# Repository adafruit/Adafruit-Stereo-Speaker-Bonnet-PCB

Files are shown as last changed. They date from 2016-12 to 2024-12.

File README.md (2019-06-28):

## Adafruit Stereo Speaker Bonnet PCB

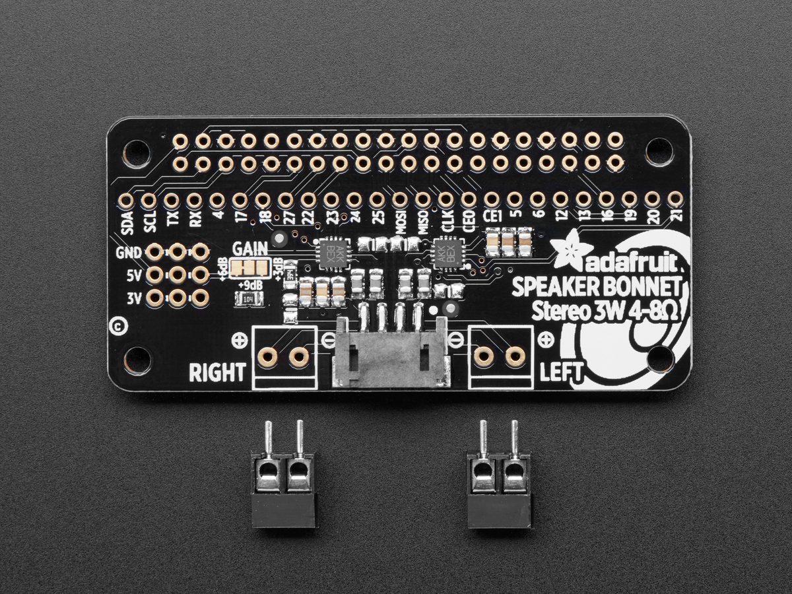
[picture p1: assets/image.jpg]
<a href="http://www.adafruit.com/products/3346"><br/>
Click here to purchase one from the Adafruit shop</a>

PCB files for the Adafruit Stereo Speaker Bonnet for Raspberry Pi. Format is EagleCAD schematic and board layout
* http://www.adafruit.com/product/3346

### Description

Hey Mr. DJ! Turn up that Raspberry Pi mix to the max with this cute 3W Stereo Amplifier Bonnet for Raspberry Pi. (It's not big enough to be an official HAT, so we called it a bonnet, you see?) It's the exact same size as a Raspberry Pi Zero but works with any and all Raspberry Pi computers with a 2x20 connector - A+, B+, Zero, Pi 2, Pi 3, etc. We've tested it out with Raspbian (the official operating system) and Retropie.

This Bonnet uses I2S a digital sound standard, so you get really crisp audio. The digital data goes right into the amplifier so there's no static like you hear from the headphone jack. And it's super easy to get started. Just plug in any 4Ω to 8Ω speakers, up to 3 Watts, run our installer script on any Raspberry Pi, reboot and you're ready to jam!

Each order comes as a fully tested and assembled PCB and 2x extra terminal blocks. No soldering required if you're using our 3 Watt speaker set, just plug and play.

### License

Adafruit invests time and resources providing this open source design, please support Adafruit and open-source hardware by purchasing products from [Adafruit](https://www.adafruit.com)!

Designed by Limor Fried/Ladyada for Adafruit Industries.

Creative Commons Attribution/Share-Alike, all text above must be included in any redistribution. See license.txt for additional details.

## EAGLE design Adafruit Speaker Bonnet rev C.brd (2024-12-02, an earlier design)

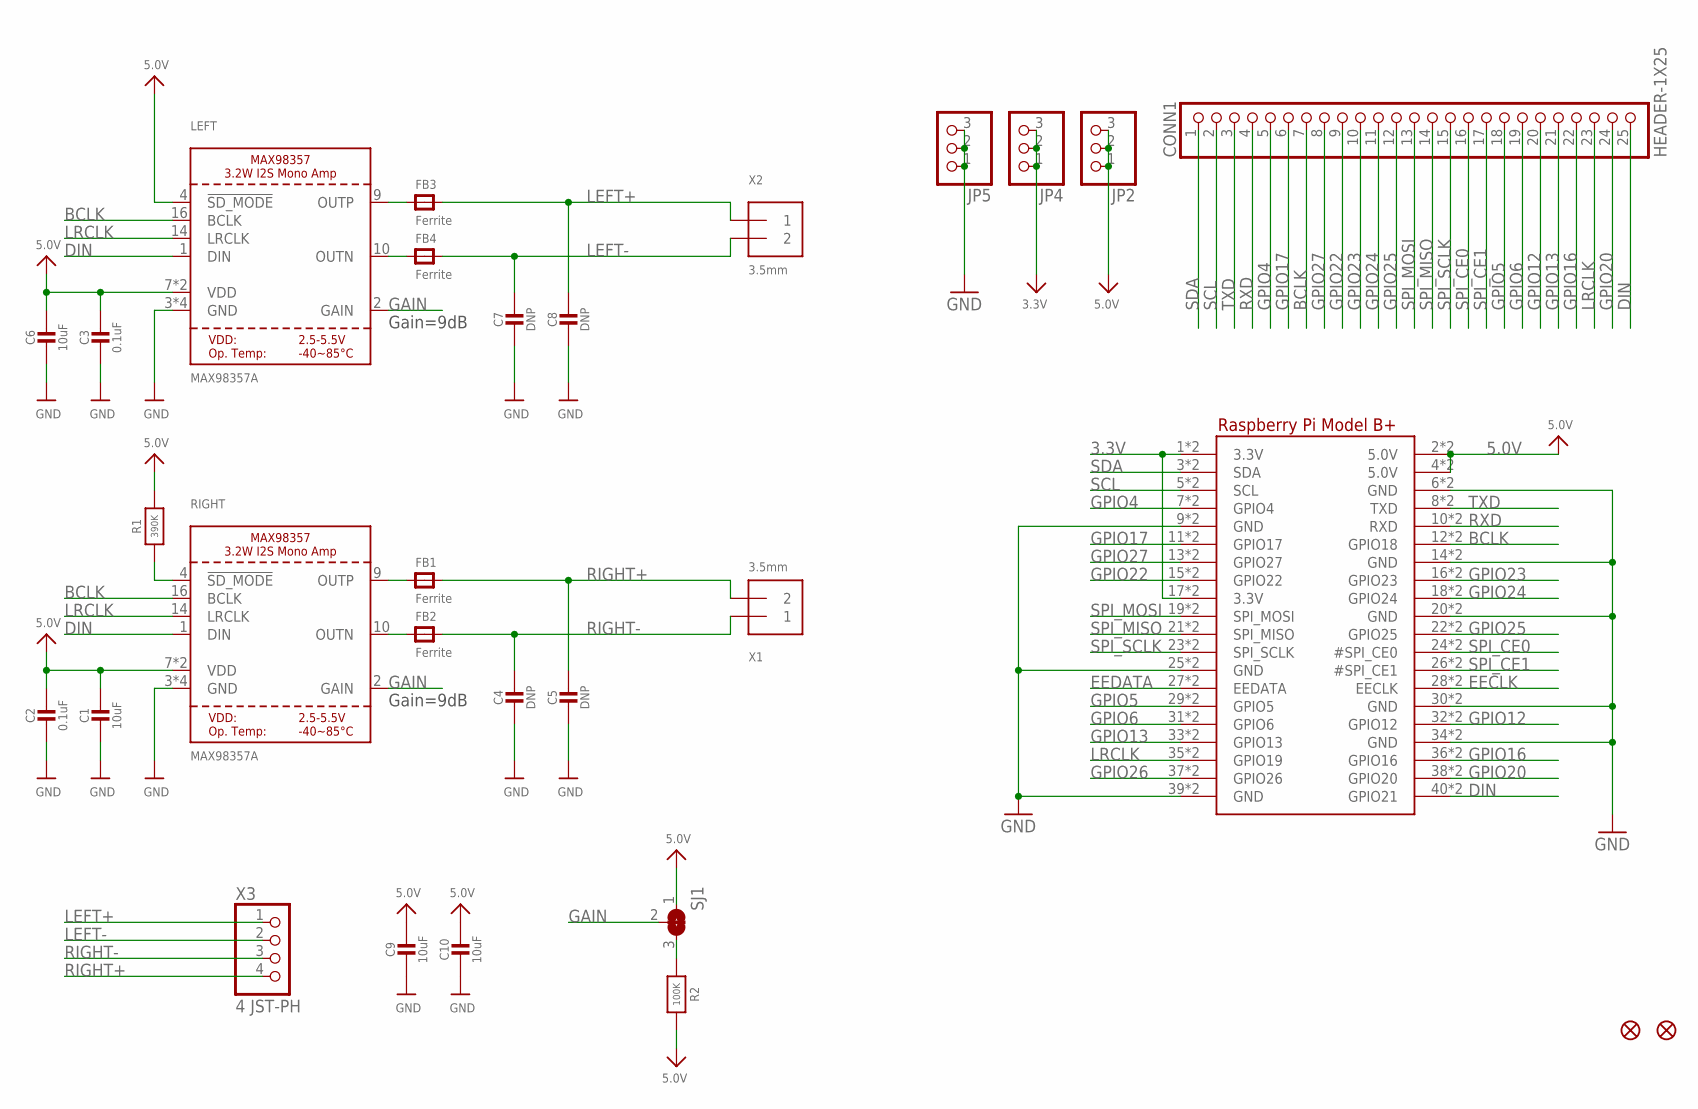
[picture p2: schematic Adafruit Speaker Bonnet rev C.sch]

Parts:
C1, C6, C9, C10: 10uF; 0805-NO
C2, C3: 0.1uF; 0805-NO
C4, C5, C7, C8: DNP; 0805-NO
CONN1: HEADER-1X25; 1X25_ROUND_70MIL
FB1, FB2, FB3, FB4: Ferrite; 0805-NO
FID1, FID2: FIDUCIAL_1MM
JP2, JP4, JP5: HEADER-1X376MIL; 1X03_ROUND_76
LEFT: MAX98357A; QFN16_3MM
R1: 390K; 0805-NO
R2: 100K; 0805-NO
RIGHT: MAX98357A; QFN16_3MM
RPI1: RASPBERRYPI_BPLUS_BONNET_THMSMT; PI_BONNET_THMSMT
SJ1: SOLDERJUMPER_2WAY; SOLDERJUMPER_2WAY_OPEN_NOPASTE
X1, X2: 3.5mm; TERMBLOCK_1X2-3.5MM
X3: 4 JST-PH; JSTPH4

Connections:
3.3V: JP4.1, JP4.2, JP4.3, RPI1.1 (3.3V), RPI1.17 (3.3V), RPI1.S1 (3.3V), RPI1.S17 (3.3V)
5.0V: C1.1, C2.1, C3.1, C6.1, C9.1, C10.1, JP2.1, JP2.2, JP2.3, LEFT.4 (!SD_MODE), LEFT.7 (VDD), LEFT.8 (VDD), R1.2, R2.2, RIGHT.7 (VDD), RIGHT.8 (VDD), RPI1.2 (5.0V), RPI1.4 (5.0V), RPI1.S2 (5.0V), RPI1.S4 (5.0V), SJ1.1
BCLK: CONN1.7, LEFT.16 (BCLK), RIGHT.16 (BCLK), RPI1.12 (GPIO18), RPI1.S12 (GPIO18)
DIN: CONN1.25, LEFT.1 (DIN), RIGHT.1 (DIN), RPI1.40 (GPIO21), RPI1.S40 (GPIO21)
EECLK: RPI1.28 (EECLK), RPI1.S28 (EECLK)
EEDATA: RPI1.27 (EEDATA), RPI1.S27 (EEDATA)
GAIN: LEFT.2 (GAIN), RIGHT.2 (GAIN), SJ1.2
GND: C1.2, C2.2, C3.2, C4.2, C5.2, C6.2, C7.2, C8.2, C9.2, C10.2, JP5.1, JP5.2, JP5.3, LEFT.3 (GND), LEFT.11 (GND), LEFT.15 (GND), LEFT.THERMAL (GND), RIGHT.3 (GND), RIGHT.11 (GND), RIGHT.15 (GND), RIGHT.THERMAL (GND), RPI1.6 (GND), RPI1.9 (GND), RPI1.14 (GND), RPI1.20 (GND), RPI1.25 (GND), RPI1.30 (GND), RPI1.34 (GND), RPI1.39 (GND), RPI1.S6 (GND), RPI1.S9 (GND), RPI1.S14 (GND), RPI1.S20 (GND), RPI1.S25 (GND), RPI1.S30 (GND), RPI1.S34 (GND), RPI1.S39 (GND)
GPIO4: CONN1.5, RPI1.7 (GPIO4), RPI1.S7 (GPIO4)
GPIO5: CONN1.18, RPI1.29 (GPIO5), RPI1.S29 (GPIO5)
GPIO6: CONN1.19, RPI1.31 (GPIO6), RPI1.S31 (GPIO6)
GPIO12: CONN1.20, RPI1.32 (GPIO12), RPI1.S32 (GPIO12)
GPIO13: CONN1.21, RPI1.33 (GPIO13), RPI1.S33 (GPIO13)
GPIO16: CONN1.22, RPI1.36 (GPIO16), RPI1.S36 (GPIO16)
GPIO17: CONN1.6, RPI1.11 (GPIO17), RPI1.S11 (GPIO17)
GPIO20: CONN1.24, RPI1.38 (GPIO20), RPI1.S38 (GPIO20)
GPIO22: CONN1.9, RPI1.15 (GPIO22), RPI1.S15 (GPIO22)
GPIO23: CONN1.10, RPI1.16 (GPIO23), RPI1.S16 (GPIO23)
GPIO24: CONN1.11, RPI1.18 (GPIO24), RPI1.S18 (GPIO24)
GPIO25: CONN1.12, RPI1.22 (GPIO25), RPI1.S22 (GPIO25)
GPIO26: RPI1.37 (GPIO26), RPI1.S37 (GPIO26)
GPIO27: CONN1.8, RPI1.13 (GPIO27), RPI1.S13 (GPIO27)
LEFT+: C8.1, FB3.2, X2.1, X3.1
LEFT-: C7.1, FB4.2, X2.2, X3.2
LRCLK: CONN1.23, LEFT.14 (LRCLK), RIGHT.14 (LRCLK), RPI1.35 (GPIO19), RPI1.S35 (GPIO19)
unnamed: FB4.1, LEFT.10 (OUTN)
unnamed: FB3.1, LEFT.9 (OUTP)
unnamed: FB2.1, RIGHT.10 (OUTN)
unnamed: FB1.1, RIGHT.9 (OUTP)
unnamed: R2.1, SJ1.3
RIGHT+: C5.1, FB1.2, X1.2, X3.4
RIGHT-: C4.1, FB2.2, X1.1, X3.3
RXD: CONN1.4, RPI1.10 (RXD), RPI1.S10 (RXD)
SCL: CONN1.2, RPI1.5 (SCL), RPI1.S5 (SCL)
SDA: CONN1.1, RPI1.3 (SDA), RPI1.S3 (SDA)
SD_MODE: R1.1, RIGHT.4 (!SD_MODE)
SPI_CE0: CONN1.16, RPI1.24 (#SPI_CE0), RPI1.S24 (#SPI_CE0)
SPI_CE1: CONN1.17, RPI1.26 (#SPI_CE1), RPI1.S26 (#SPI_CE1)
SPI_MISO: CONN1.14, RPI1.21 (SPI_MISO), RPI1.S21 (SPI_MISO)
SPI_MOSI: CONN1.13, RPI1.19 (SPI_MOSI), RPI1.S19 (SPI_MOSI)
SPI_SCLK: CONN1.15, RPI1.23 (SPI_SCLK), RPI1.S23 (SPI_SCLK)
TXD: CONN1.3, RPI1.8 (TXD), RPI1.S8 (TXD)

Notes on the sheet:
Gain=9dB

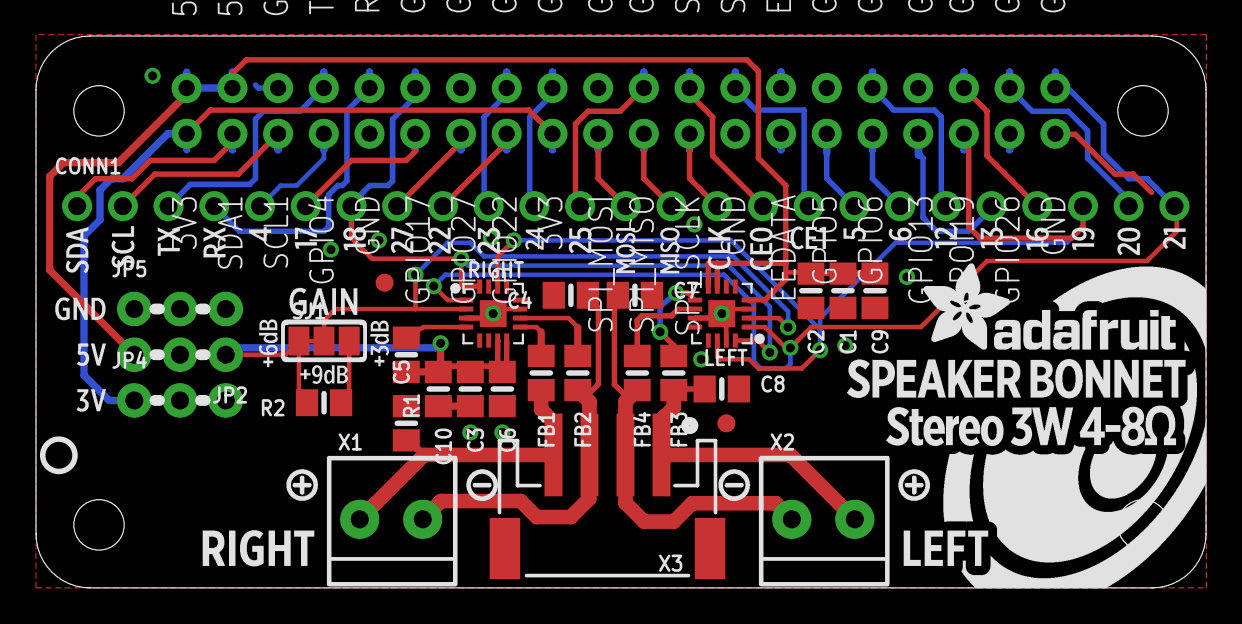
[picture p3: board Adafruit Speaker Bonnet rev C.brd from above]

Board: 2 copper layers, 65.0 x 30.7 mm, 31 parts (0 on the bottom side), 42 nets.

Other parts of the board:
U$11: PCBFEAT-REV-040
U$30: BONNET_SPEAKER_REVB

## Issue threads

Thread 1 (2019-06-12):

Hope here is the place to post this... no doc for the gain setting.

iMartyn, 2019-06-12:
Following https://learn.adafruit.com/adafruit-speaker-bonnet-for-raspberry-pi makes the hat work, but no information about the gain pads... cut? bridge? etc.

ladyada, 2019-06-12:
https://learn.adafruit.com/adafruit-max98357-i2s-class-d-mono-amp/pinouts#gain-2-14
has some info - also check the datasheet!

iMartyn, 2019-06-12:
Perfect, thanks, although fyi gain direct to gnd makes the pi not boot.  I went with the 100k to solve this as I'm fine with the extra gain, but if someone wants that in-between setting, it's a problem.

Closed 2019-06-12.

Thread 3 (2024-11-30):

speaker bonnet right / left channel fix

mikeysklar, 2024-11-30:
The right / left stereo playback works well with a 220k ohm value for R1 connected to SD_MODE. The current 390k results in one side playing both right/left channels.

The current work around is to [stack a 470k resistor on R1](https://forums.adafruit.com/viewtopic.php?p=1037187#p1037187) to drop the resistance to 220k ohm or swap it. [PR# 2](https://github.com/adafruit/Adafruit-Stereo-Speaker-Bonnet-PCB/pull/2) also mentioned this

Please update the sch / pcb files.

mikeysklar, 2024-12-02:
Thanks, looks good with 220k R1.

Closed 2024-12-02.

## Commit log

2021-12-13 Add rev C.
    [Adafruit Speaker Bonnet Original.brd, Adafruit Speaker Bonnet Original.sch]
2024-12-02 add rev D
    [Adafruit Speaker Bonnet rev C.brd, Adafruit Speaker Bonnet rev C.sch, Adafruit Speaker Bonnet rev D.brd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]

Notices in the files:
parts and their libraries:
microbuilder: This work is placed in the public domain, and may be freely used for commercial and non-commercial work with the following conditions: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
